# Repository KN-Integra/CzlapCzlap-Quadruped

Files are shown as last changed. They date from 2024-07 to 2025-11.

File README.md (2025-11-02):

# CzlapCzlap-Quadruped
A grant project for a quadrupedal walking robot by members of the KN Integra.  
CzłapCzap is a quadrupedal walking robot designed for research, prototyping, and educational purposes.

* **Electronics** – includes PCB design files (.gbr) viewable in KiCad EDA, along with a brief description of the custom schematic for the robot's control electronics.
* **Mechanics** – contains CAD models and assembly diagrams illustrating the robot's structure and joint configuration.
* **Software** – implements the control system using ROS2 and Python, with modular nodes for motion planning, leg kinematics, sensor handling, and hardware/simulation interfaces. Main code is available in a private repository. The architecture allows seamless switching between simulation (PyBullet) and real hardware while maintaining unified control logic.

## September 2025

<a href="_files/20250913_161538.mp4">
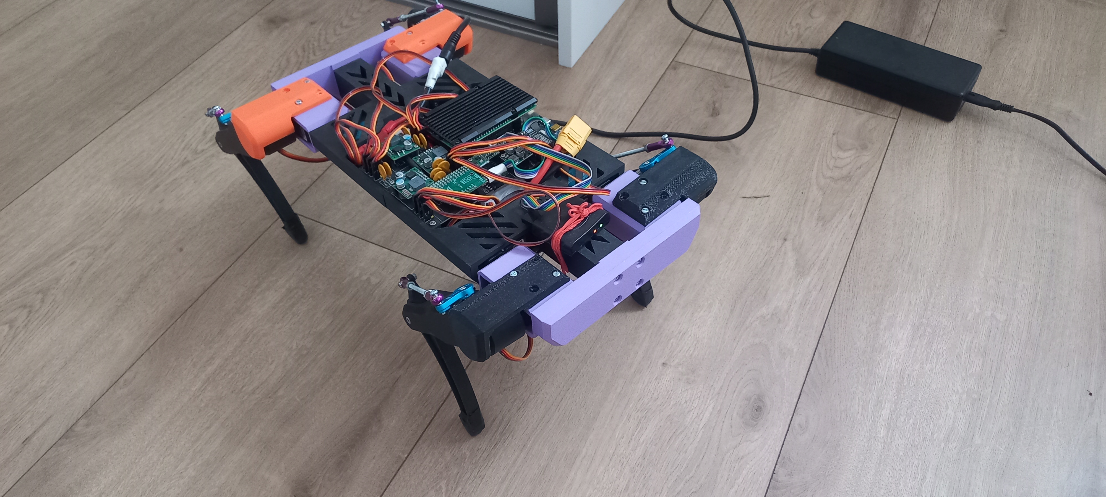
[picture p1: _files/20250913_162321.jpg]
Watch Demo
  
</a>

### Videos

Watch Demo

Watch Demo
## September 2024



## May 2024


## January 2024



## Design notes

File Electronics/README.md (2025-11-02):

# Electronics

PCB v.0.1

The electronic part of the robot was designed using the Kicad EDA software. The following components were used for this project:

- Feetech FI7635M Servos - 180-degree rotation
- Pololu D36V50F7 Converters
- Raspberry Pi 4B 4GB
- Pololu Maestro Mini 16-channel servo controller (a 12-channel version can also be connected)
- USB-C, micro-HDMI, and USB mini-B ports - to allow external connection to the robot without needing to remove the Raspberry Pi or the servo controller
- I2C and SPI modules - for taking measurements using an external ADC converter, accelerometer, communicating with a Gamepad, current sensors, or LED drivers
- Voltage level converter module - for communication between the Raspberry Pi and the Pololu Maestro Mini controller

## Connection Schematic



## PCB Layout (Traces View) and 3D View




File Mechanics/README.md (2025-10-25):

# Quadruped Robot - Inverse Kinematics

Python implementation of inverse kinematics for a quadruped robot.

The program calculates compensation for each leg to enable the robot to rotate by a defined angle around a chosen axis.

## GUI and visualization view

View of default and rotated position.

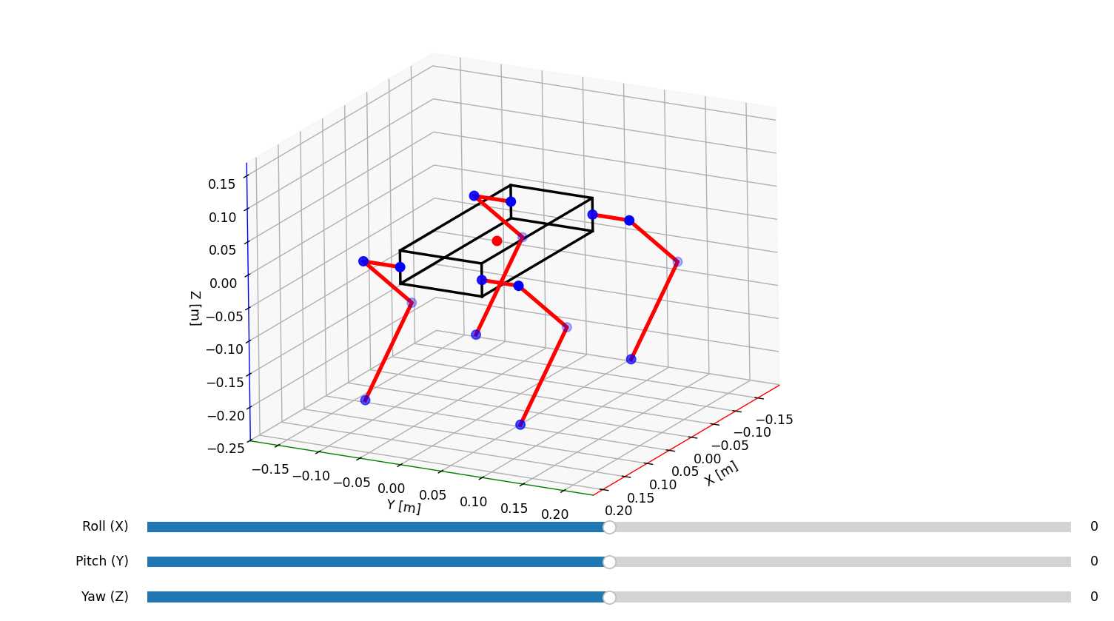
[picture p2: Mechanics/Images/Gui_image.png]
Default position

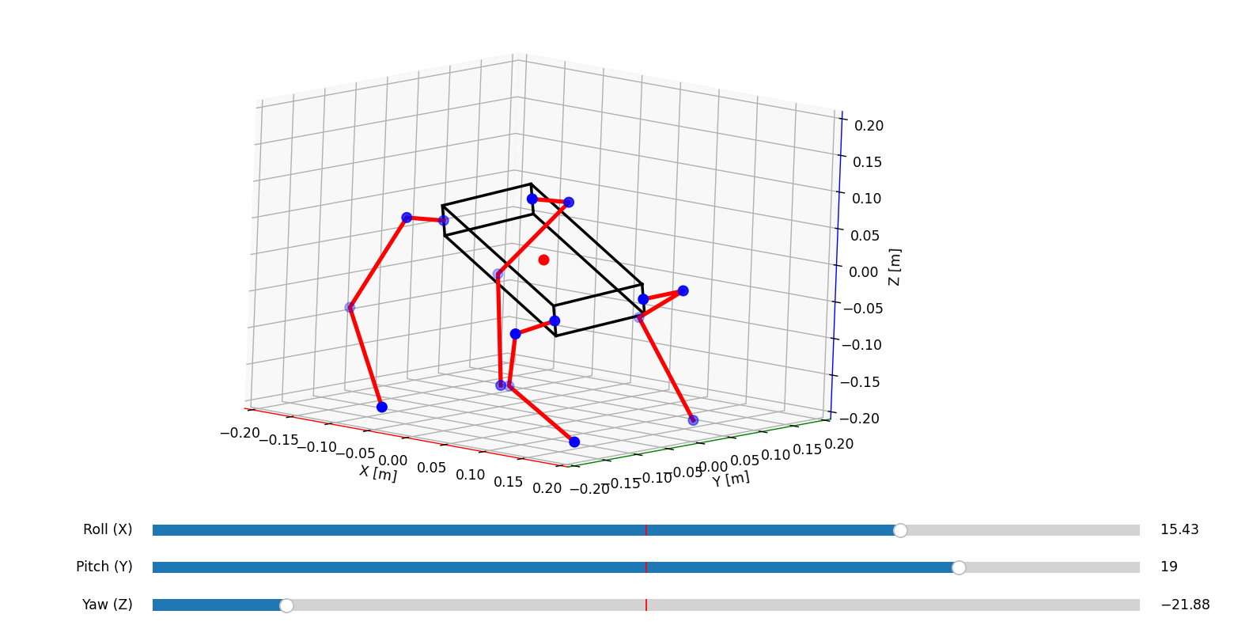
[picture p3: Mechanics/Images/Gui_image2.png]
Rotated position


## Equations and Diagrams

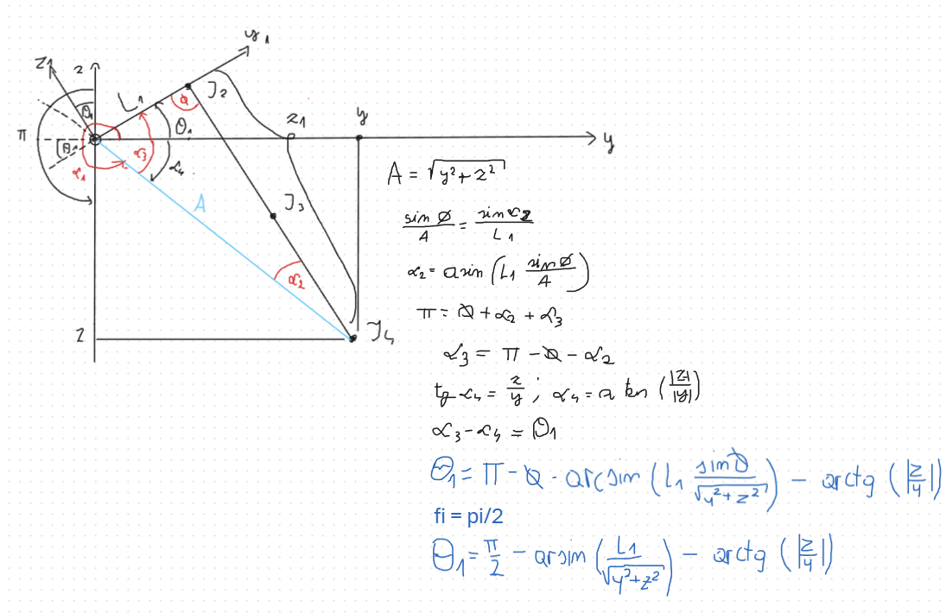
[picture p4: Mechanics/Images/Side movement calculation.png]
Front view of the robot (left front leg)

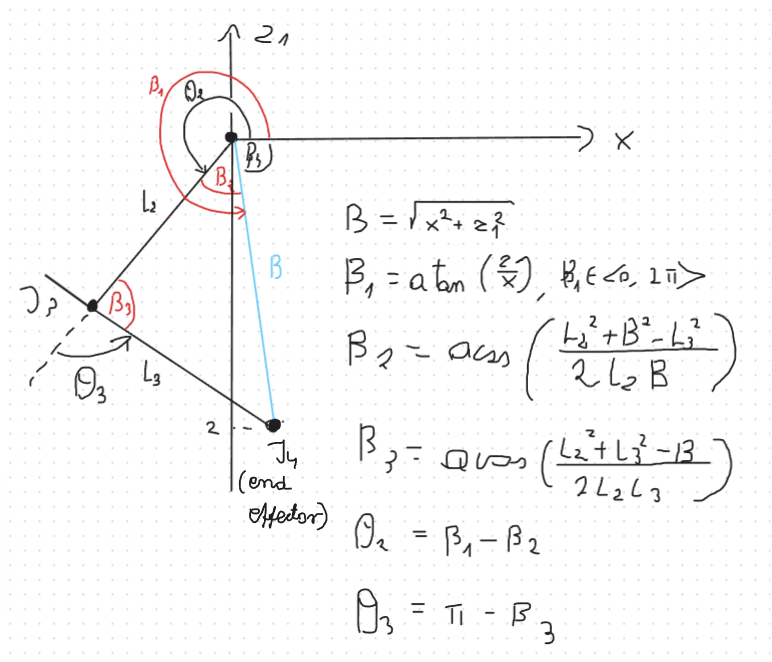
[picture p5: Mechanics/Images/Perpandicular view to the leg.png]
Perpendicular view to the ZX plane of the leg (left front leg)


We always calculate angles θ₂ and θ₃ by looking perpendicular to the leg. Therefore, we need to rotate our coordinate system by angle θ₁ to obtain this perpendicular view (see `quadruped_inverse.py`, line 114).

## Mechanical design

The quadruped robot’s structure is fully 3D-printed, with both the body and legs assembled using threaded brass inserts and screws to ensure strong and precise connections.
All joint axes are supported by machine bearings, which provide smooth and durable movement.
The leg tips are printed from TPU material, improving traction and shock absorption during walking.
To increase rigidity, the robot’s body is reinforced with two threaded rods running along its entire length, ensuring structural stability under load.

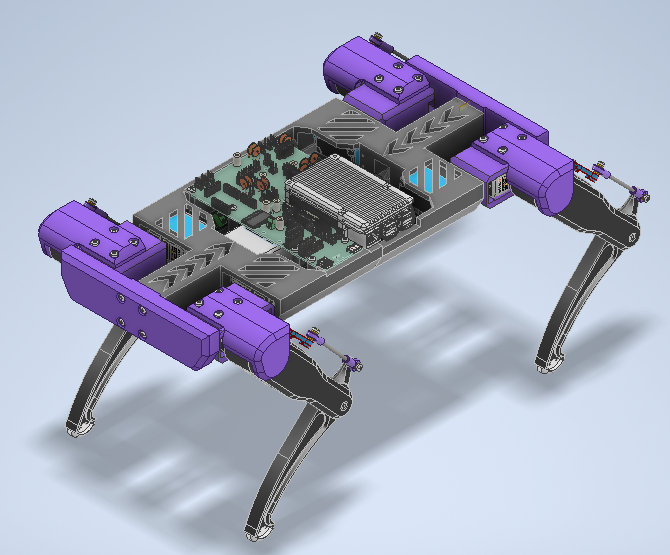
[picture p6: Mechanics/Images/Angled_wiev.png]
Robot 3D CAD model

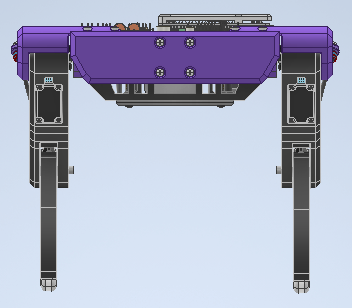
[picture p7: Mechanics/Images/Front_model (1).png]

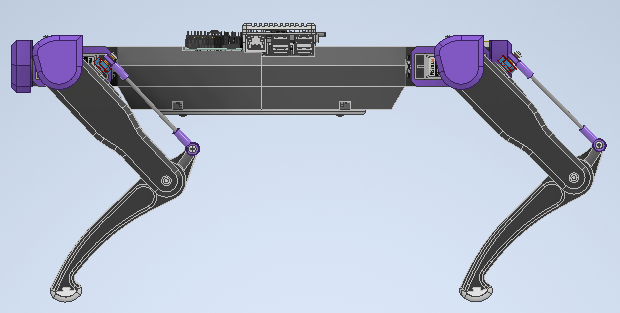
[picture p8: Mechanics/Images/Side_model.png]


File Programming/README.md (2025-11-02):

# CzlapCzlap-Quadruped
A grant project for a quadrupedal walking robot developed by members of the KN Integra student research group.

## ROS2 Packages and Nodes

The control software for the quadruped robot **CzłapCzłap** is organized into several ROS2 packages.  
Each package is responsible for a specific layer of the control architecture - from user input and motion planning to hardware or simulation interfaces.  
This modular design allows for seamless switching between real hardware and simulation environments while maintaining a unified communication structure.

Below is a brief overview of the key packages and their corresponding nodes.

### motion_planner
Implements gait generation, trajectory planning, and motion coordination.  
Main node: `motion_planner_node`  
- Generates leg trajectories based on selected gait configuration.  
- Uses IMU data for stabilization and adaptive correction.  
- Integrates modules: `gait_planner`, `trajectory_planner`, `state_machine`.

### leg_controller
Handles inverse kinematics for all legs.  
Main node: `leg_IK_node`  
- Subscribes to `/global_leg_coordinates`.  
- Computes joint angles and publishes `/global_leg_angles`.

### servo_controller
Low-level interface for servo communication via UART.  
Main node: `servo_controller_node`  
- Converts joint angles to PWM signals.  
- Sends commands to servo driver and manages calibration offsets.

### robot_control
Provides user input interfaces.  
Nodes: `keyboard_node`, `gamepad_node`  
- Publishes control events to the motion planner.  
- Interfaces with keyboard or SPI-based gamepad.

### czlapczlap_sim
Simulation environment using PyBullet.  
Main node: `czlapczlap_sim_node`  
- Loads URDF model and simulates physical behavior.  
- Subscribes to `/global_leg_angles` and visualizes robot motion.  
- Shares the same topics as hardware for unified testing.

### sensor_interface
Manages sensor data acquisition and filtering.  
Nodes: `imu_node`, `adc_node`  
- `imu_node`: reads IMU data, applies Madgwick filter, publishes `/imu_values`.  
- `adc_node`: reads analog data and publishes `/adc_data`.

## System Architecture
Below is the architecture of the control system for the quadruped robot **CzłapCzłap**.  
The diagram illustrates the communication flow between ROS2 nodes and the modular structure of the software.  
The system supports control of both the **physical robot** and its **PyBullet simulation**, using the same message format and communication interface - `/global_leg_angles`.
This allows seamless switching between hardware testing and virtual experiments without modifying the control logic.

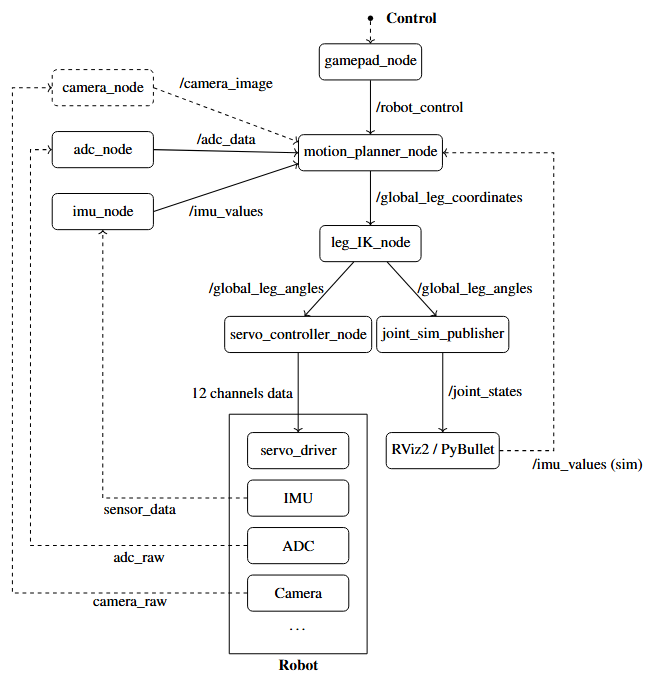
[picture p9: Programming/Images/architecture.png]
architectures

---

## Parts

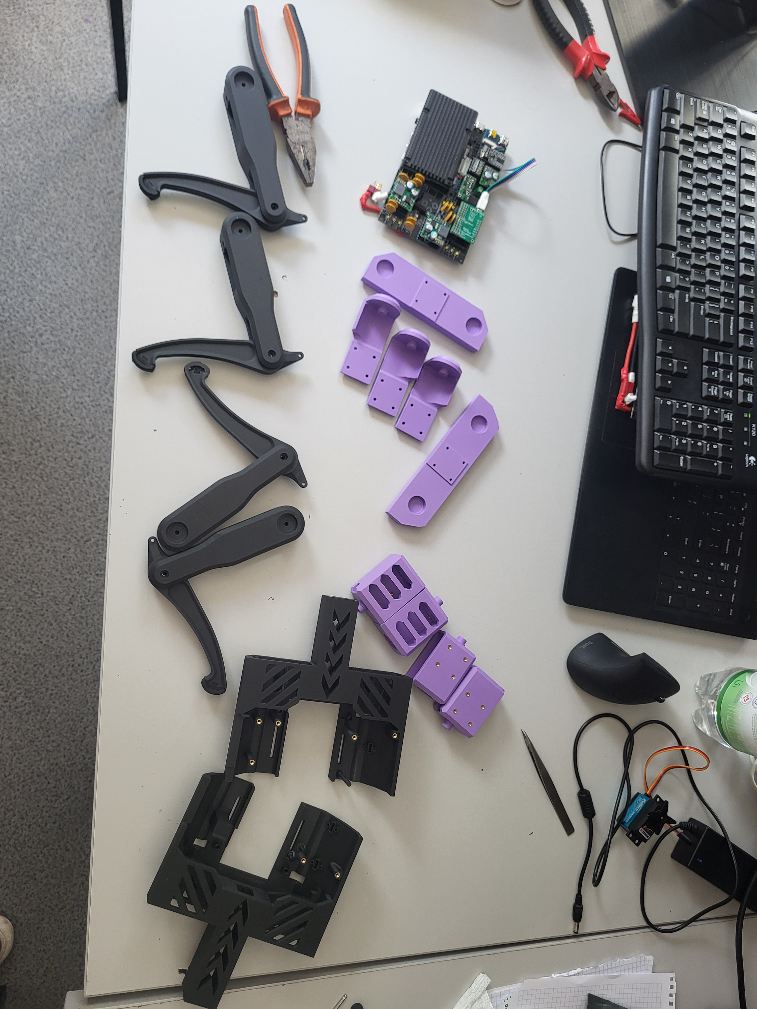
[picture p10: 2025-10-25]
Mechanics/Images/Robot_in_parts.jpg

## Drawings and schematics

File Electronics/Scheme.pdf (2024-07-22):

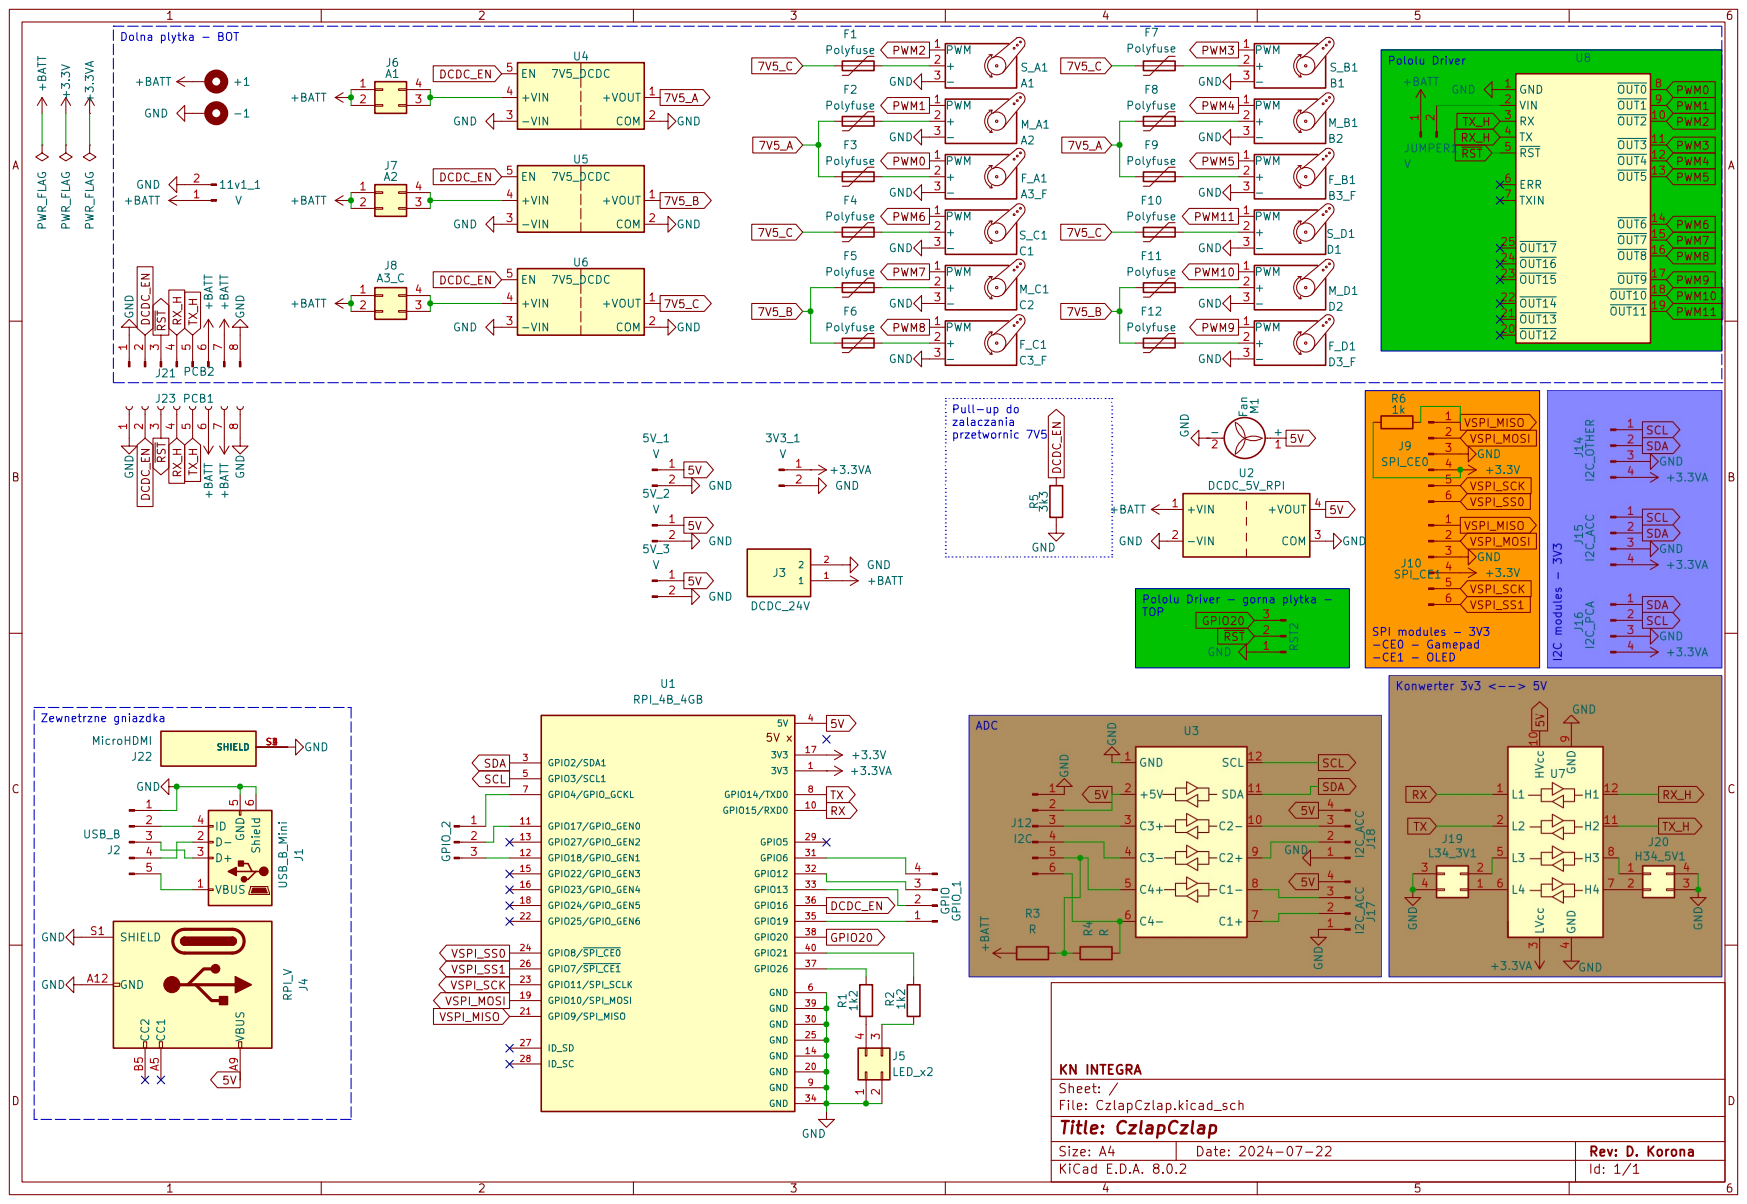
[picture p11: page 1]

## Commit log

2024-07-22 add gerber files
    [CzlapCzlapBOT-B_Cu.gbr, CzlapCzlapBOT-B_Mask.gbr, CzlapCzlapBOT-B_Paste.gbr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]
2024-07-22 added schematics
2025-10-25 Aktualizacja mechaniki
    Wstawione zostały fotki i krótki opis mechaniki wraz z kinematyką
